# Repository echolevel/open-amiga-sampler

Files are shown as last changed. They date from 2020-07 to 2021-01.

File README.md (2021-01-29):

# OPEN AMIGA SAMPLER

## Open source schematics, parts lists and documentation for building a generic 8bit/mono Amiga parallel port sound sampler

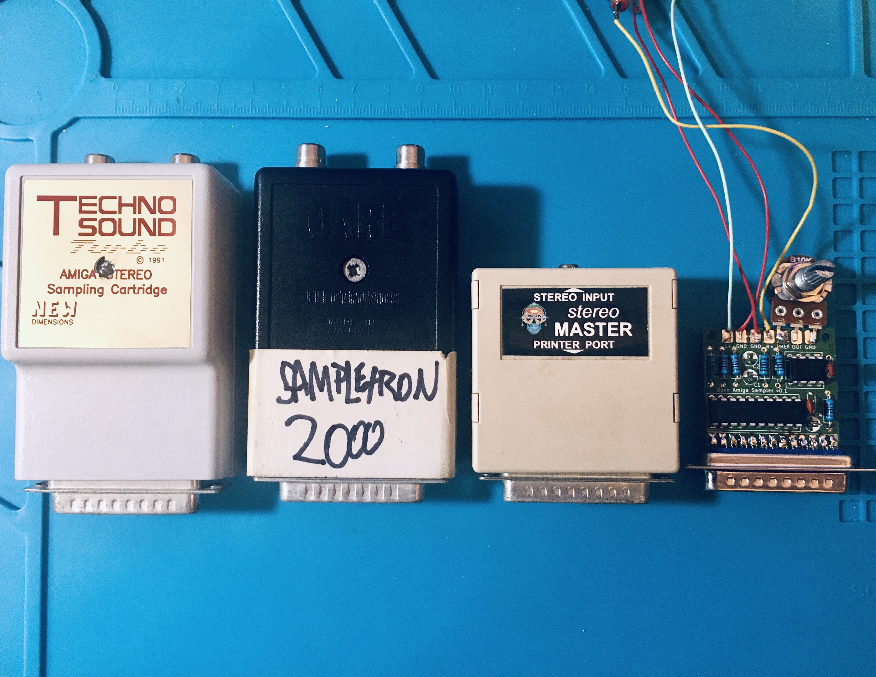
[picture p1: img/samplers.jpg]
samplers


Amiga parallel port sound samplers are simple hardware devices from the late 80s/early 90s which allowed users to digitally record audio to their home computer and represented a revolution in DIY music production. They were once cheap and ubiquitous, but they're increasingly expensive and hard to find as the popularity of retro computing continues to rise.

OAS is an open source PCB and case design for a cartridge-style mono sampler geared towards use with Soundtracker and Protracker-style software. It is easy to make, cheap to produce, and thanks to its built in preamp with hardware gain control it can deliver higher quality results than the average vintage sampler.

Please read the wiki for more information!

### [OAS Wiki Home](https://github.com/echolevel/open-amiga-sampler/wiki)

### Background

***
* [What are Amiga samplers?](https://github.com/echolevel/open-amiga-sampler/wiki/What-are-Amiga-samplers%3F)
* [Why build more?](https://github.com/echolevel/open-amiga-sampler/wiki/Why-build-more%3F)

### Development

***
* [How do they work?](https://github.com/echolevel/open-amiga-sampler/wiki/How-do-they-work%3F)
* [⚠️ WARNING](https://github.com/echolevel/open-amiga-sampler/wiki/%E2%9A%A0%EF%B8%8F-WARNING)
* [That WARNING sounds serious. How did you test your design without risking Amiga hardware?](https://github.com/echolevel/open-amiga-sampler/wiki/That-WARNING-sounds-serious.-How-did-you-test-your-design-without-risking-your-Amiga-hardware%3F)
* [Why is this sampler design mono, not stereo?](https://github.com/echolevel/open-amiga-sampler/wiki/Why-is-this-sampler-design-mono,-not-stereo%3F)
* [What's the aim in terms of quality and application?](https://github.com/echolevel/open-amiga-sampler/wiki/What's-the-aim-in-terms-of-quality-and-application%3F)
* [What about those edge cases? Who is OAS not aimed at?](https://github.com/echolevel/open-amiga-sampler/wiki/What-about-those-edge-cases%3F-Who-is-OAS-not-aimed-at%3F)
* [How compatible is OAS with existing software? (Work in progress, submissions welcome)](https://github.com/echolevel/open-amiga-sampler/wiki/How-compatible-is-OAS-with-existing-software%3F-(Work-in-progress,-submissions-welcome))
* [Current status](https://github.com/echolevel/open-amiga-sampler/wiki/Current-status)

### Production & Availability

***
* [Availability](https://github.com/echolevel/open-amiga-sampler/wiki/Availability)
* [DIY assembly](https://github.com/echolevel/open-amiga-sampler/wiki/DIY-assembly)

### Appendices

***
* [Appendix A: Sample rates deep-dive](https://github.com/echolevel/open-amiga-sampler/wiki/Appendix-A:-Sample-rates-deep-dive)
* [Appendix B: Sampling duration deep-dive](https://github.com/echolevel/open-amiga-sampler/wiki/Appendix-B:-Sampling-duration-deep-dive)

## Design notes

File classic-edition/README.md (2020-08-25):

# OPEN AMIGA SAMPLER CLASSIC EDITION

Kicad files for the original through-hole version of Open Amiga Sampler and OpenSCAD/STL files for the 3D-printable case.

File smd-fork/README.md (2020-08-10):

# OPEN AMIGA SAMPLER

## Overview

Here you can find the schematic and a PCB layout for Open Amiga Sampler in KiCAD format. Additionally, the schematic is available as a PDF.
The design consists of an inverting opamp circuit with variable gain which feeds an ADC. The DB25's strobe pin is connected to the ADC and initiates a conversion when it goes low. The ADC's outputs are connected to the data pins of a DB25 connector, which also provides power and ground. 

## BOM

* 1x Maxim ADC0820CCM+ (SOIC-20 Package) - mouser P/N  700-ADC0820CCM
* 1x Microchip MCP6001T-I/OT (SOT-23-5 package) - mouser P/N 579-MCP6001T-I/OTVAO
* 1x DB25 plug connector
* 2x RCA receptacles
* 1x 0805 330ohm resistor 
* 5x 0805 1kohm resistors
* 1x 10kohm exponential potentimeter
* 1x 4x5.3mm 47uf electrolytic capacitor
* 2x 10uf Tantalum Case A or 1206 capacitors
* 2x 0805 0.1uf capacitors

### Substitutions

The 10kohm potentiometer will give between 1x and 10x gain. A larger potentiometer can be substituted to enable a large maxium gain. The RCA receptacles can be replaced by a stereo jack receptacle if preferred. It is likely that both ICs could be substituted for similar chips with identical pinouts, but these are the models that we have tested and confirmed to work.

## Soldering

All on board components are surface mount but nothing smaller than 0805 and should be relatively easy to solder even for someone with a good base level of soldering and a bit of practice. The MCP6001 is a SOT-23-5 with a ~1mm pitch and represents the smallest component on the board. the Pot and RCA receptacles can be soldered with wire leads from the through hole pads

## Case

This board is intended to fit inside a standard DB25 D-Sub shell. (a regular common grey one) but due to it's small size, a larger enclosure can also be used and a custom 3D printed one may get produced as well.

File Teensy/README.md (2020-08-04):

## Teensy Amiga Sampler Tester

We used a Teensy 3.5 dev board to build a circuit that let us test original sampler carts, and also our prototype builds of OAS, without the risk of damaging our Amiga hardware.

The .ino is annotated with hopefully enough clues to get you going, though I'll make a diagram when I have time.

Some notes:
* the use of non-sequential digital pins for reading data is due to the way GPIO is laid out in the bare-metal Teensy architecture - using the pins I specify allows you to do a FAST byte read (doing it the slow way is too slow for our purposes)
* you don't really need to be alternating the STATUS and PAPER_OUT high/low if you're testing a mono sampler, as these are used to flip most cheap stereo samplers' quad bilateral switch ICs (to alternate the ADC's input providing data bytes in stereo with only one ADC). Setting one as high and the other as low and then leaving them should be fine. You can also do this to get mono (ie either left or the right channel) audio from a stereo sampler
* the STROBE, STATUS and PAPER_OUT signals need to be raised from Teensy's 3.3v output level to the 5v that the Amiga needs. This can be done with a bi-directional logic level converter, ideally with 4 channels. You can feed the converter the 5v it needs from a small hole next to the Teensy 3.5's USB input (refer to your Teensy's documentation). This hole usually won't align to a breadboard, so it's probably best to solder your 5v wire to it..
* be sure to wire up EVERY ground pin on the DB25 connector properly (see the Amiga parallel pinout below)
* the DB25 connector also needs 5v - again, get this from the Teensy's USB input.

### Amiga Parallel Pin Reference

Remember: we're mimicking an Amiga's parallel port so our female DB25 connector, wired up to the Teensy, is what a sampler sees when it's plugged into the real thing.

| DB25 Pin | Teensy pin | Purpose | Notes |
|-----|----|---|---|
|1| 9 | STROBE | must be at +5v reference level |
|2| 2 | Data 0 | |
|3| 14 | Data 1 | |
|4| 7 | Data 2 | |
|5| 8 | Data 3 | |
|6| 6 | Data 4 | |
|7| 20 | Data 5 | |
|8| 21 | Data 6 | |
|9| 5 | Data 7 | |
|10| | ACK | unused |
|11| | BUSY | unused |
|12| 10 | PAPER_OUT | must be at +5v ref level |
|13| 11 | SELECT | must be at +5v ref level |
|14| VUSB | +5V |
|15| | | not connected  |
|16| | RESET | unused |
|17| GND | GROUND |
|18| GND |  GROUND |
|19| GND |  GROUND |
|20| GND |  GROUND |
|21| GND |  GROUND |
|22| GND |  GROUND |
|23| GND |  GROUND |
|24| GND |  GROUND |
|25| GND |  GROUND |

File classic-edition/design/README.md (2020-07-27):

# OPEN AMIGA SAMPLER

## Overview

Here you can find the schematic and a PCB layout for Open Amiga Sampler in KiCAD format. Additionally, the schematic is available as a PDF.
The design consists of an inverting opamp circuit with variable gain which feeds an ADC. The DB25's strobe pin is connected to the ADC and initiates a conversion when it goes low. The ADC's outputs are connected to the data pins of a DB25 connector, which also provides power and ground. 

## BOM

* 1x Maxim ADC0820CCN+
* 1x Microchip MCP6002-I/P
* 1x DB25 plug connector
* 2x RCA receptacles
* 1x 330ohm resistor
* 5x 1kohm resistors
* 1x 10kohm exponential potentimeter
* 1x 47uf capacitor
* 2x 10uf capacitors
* 2x 0.1uf capacitors

### Substitutions

The 10kohm potentiometer will give between 1x and 10x gain. A larger potentiometer can be substituted to enable a large maxium gain. The RCA receptacles can be replaced by a stereo jack receptacle if preferred. It is likely that both ICs could be substituted for similar chips with identical pinouts, but these are the models that we have tested and confirmed to work.

## Soldering

All components are through-hole and should be relatively easy to solder even for a novice. Some components can be soldered to the back of the board and folded down to make the overall unit slimmer. One possible configuration is to solder C1, C2, C3 and C5 to the back of the board, and fold C4 down onto the front footprint of C3. We recommend soldering the DB25 connector first, followed by the passive components and leads, and finally the ICs. This reduces the chance of damaging the ICs with excessive heat.

## Case

We are working on a compact 3D printed case in an approriate form factor for all Amiga computers. You may be able to find an appropriate enclosure to build the device into, but if you intend to plug the device directly into your Amiga you will need to make sure that ports adjacent to the parallel port will not be impeded.

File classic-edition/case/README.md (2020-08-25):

# OPEN AMIGA SAMPLER CLASSIC EDITION CASE

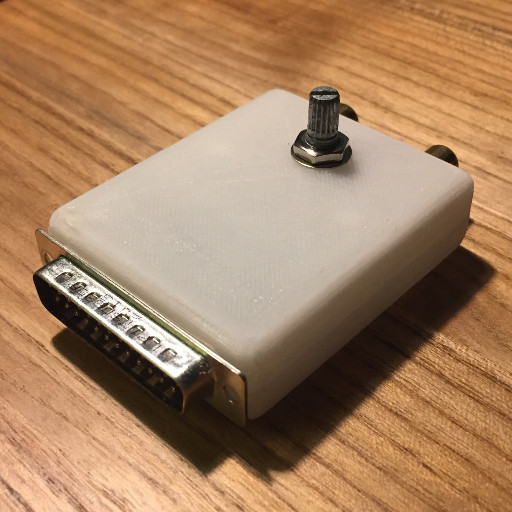
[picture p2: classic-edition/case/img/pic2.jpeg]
front

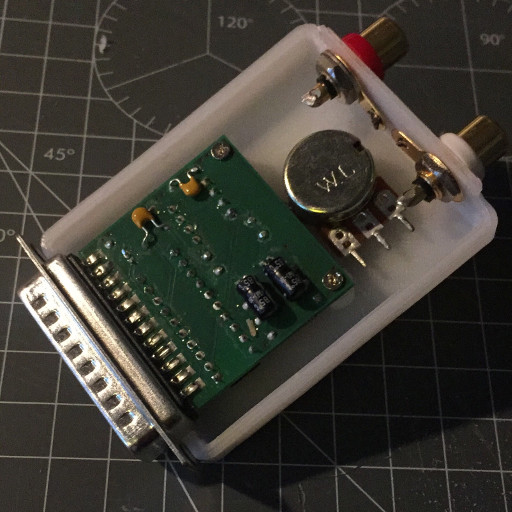
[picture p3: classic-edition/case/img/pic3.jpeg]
back

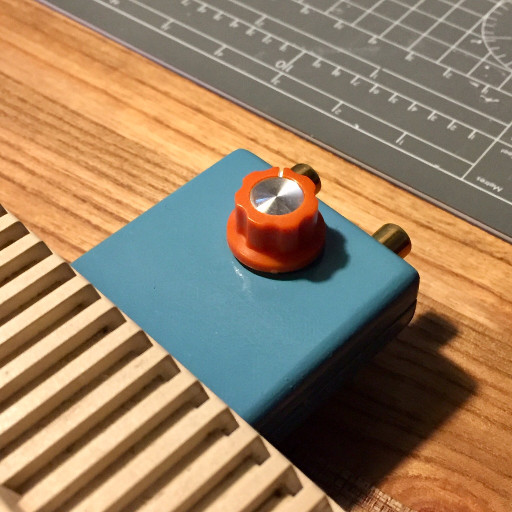
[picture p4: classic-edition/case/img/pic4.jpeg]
painted


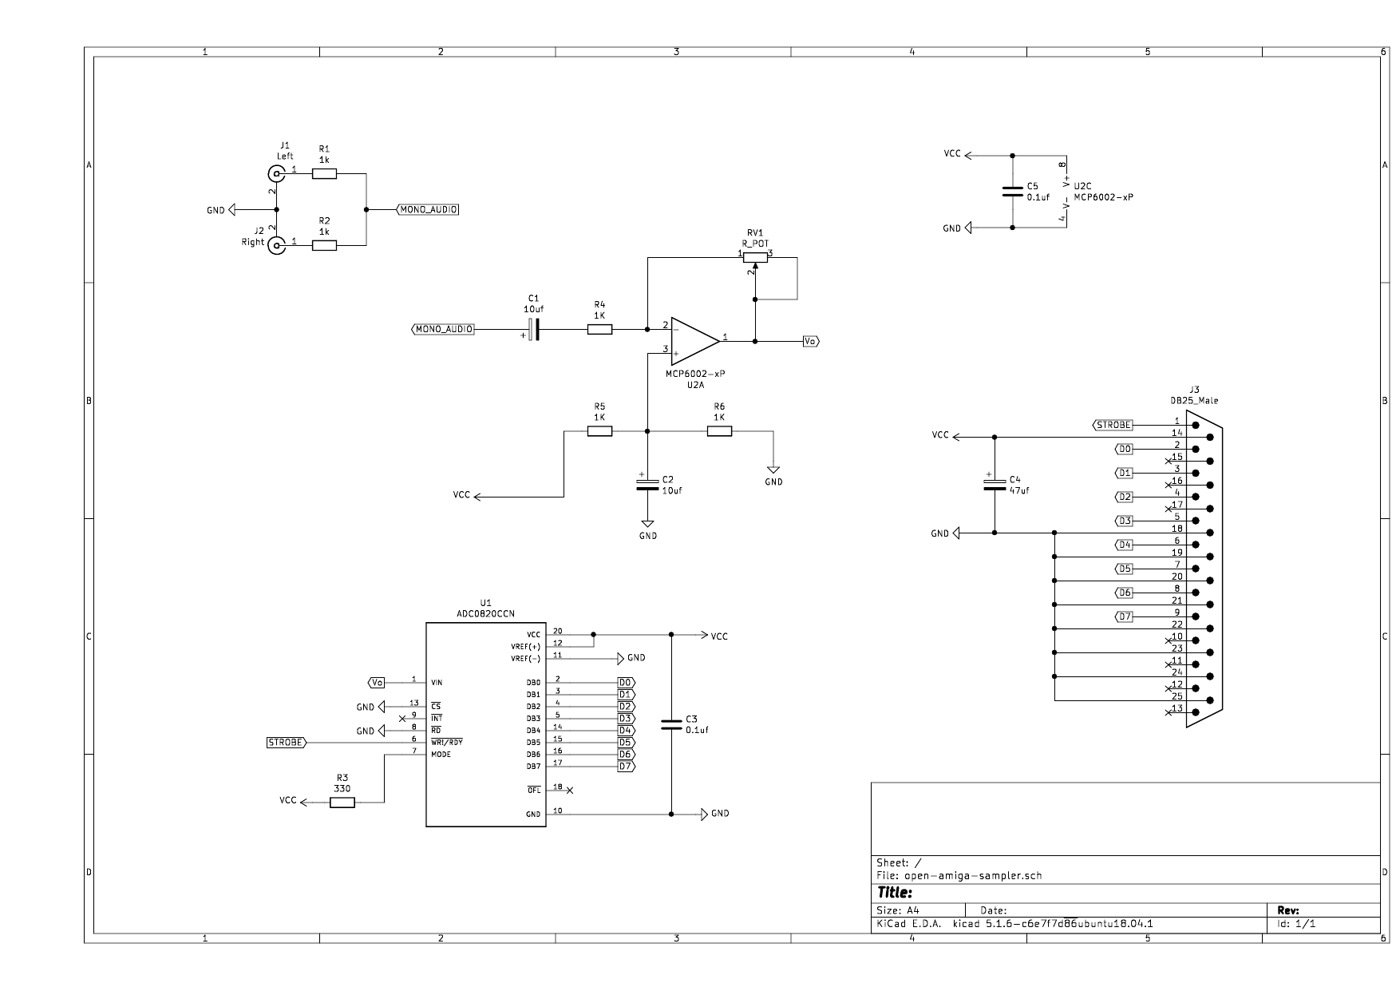
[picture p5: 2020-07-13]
img/schematic.png

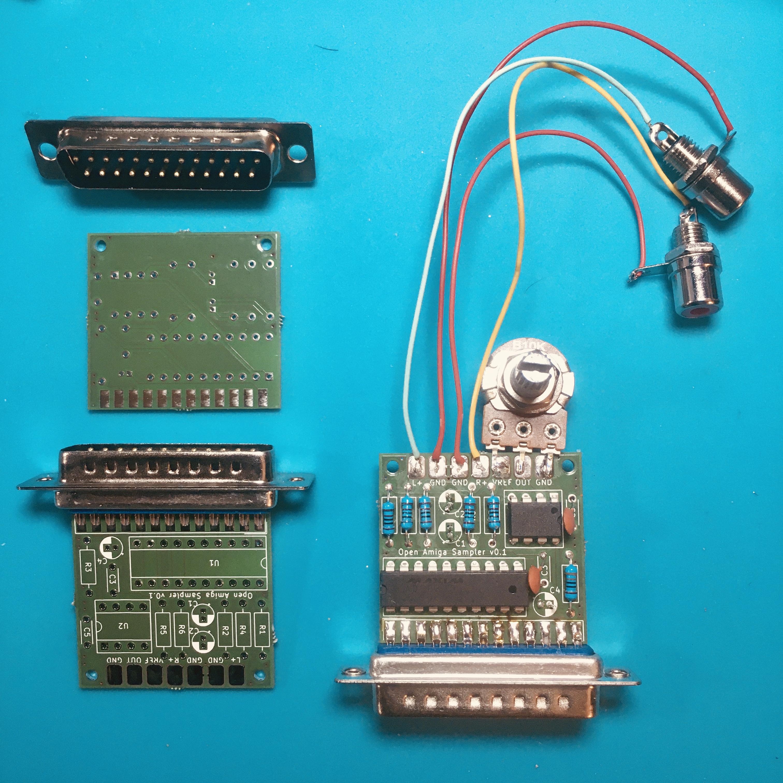
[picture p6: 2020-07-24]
img/oas_pcb.jpg

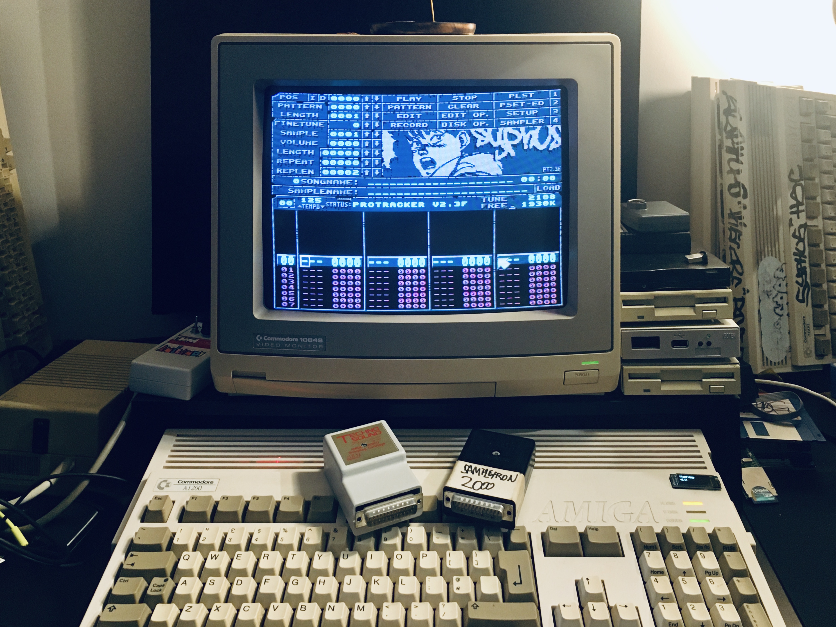
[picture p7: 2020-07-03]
img/amigawide.jpg

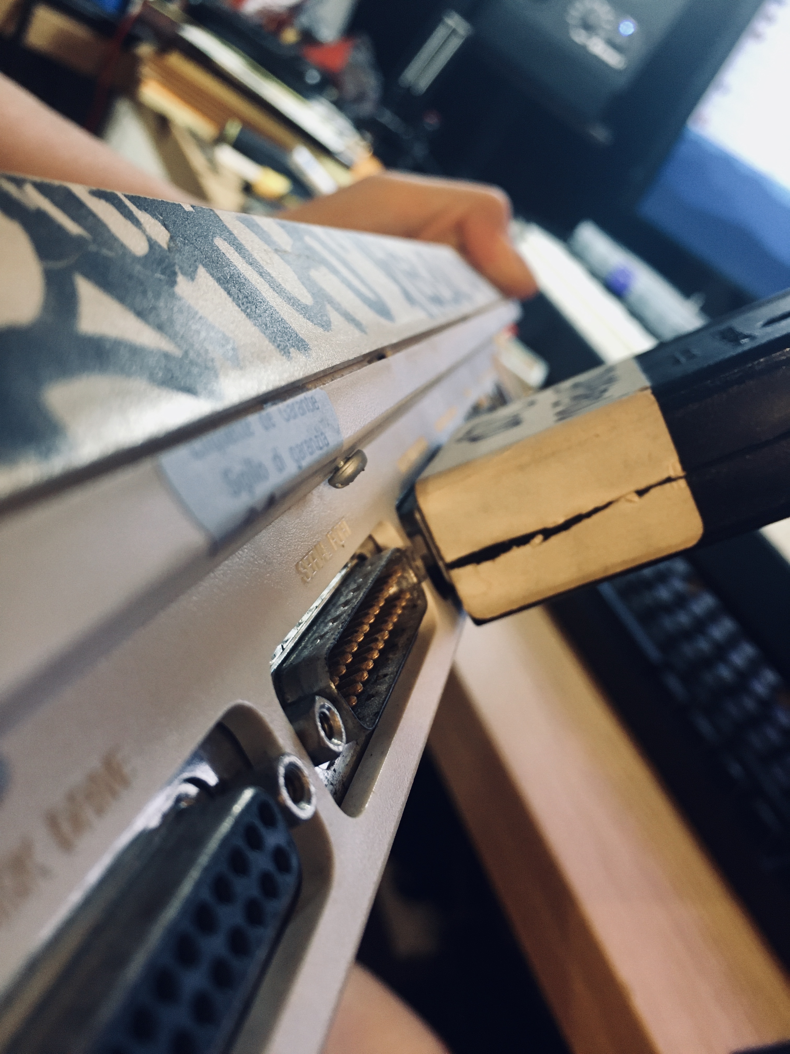
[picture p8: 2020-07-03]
img/amigaio.jpg

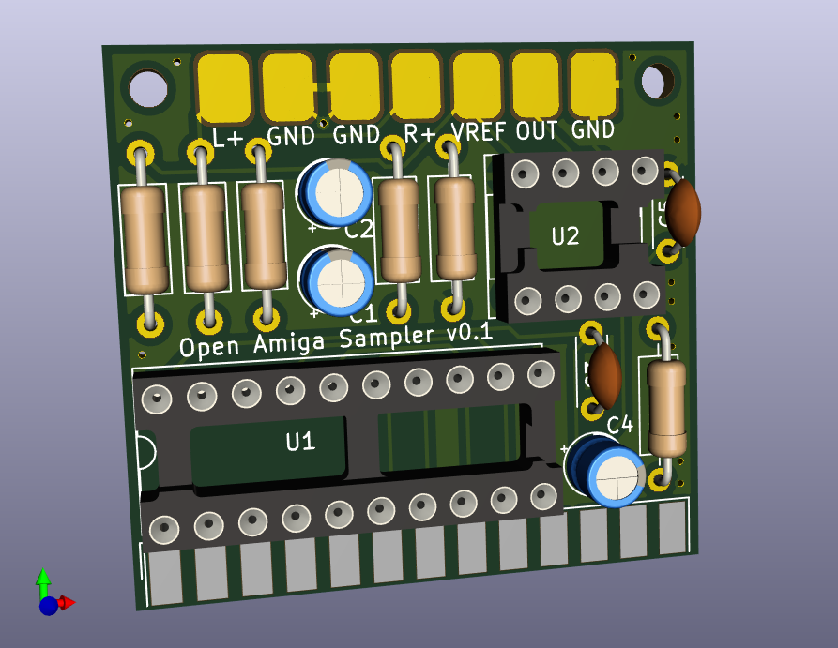
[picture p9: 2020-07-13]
img/pcb.png

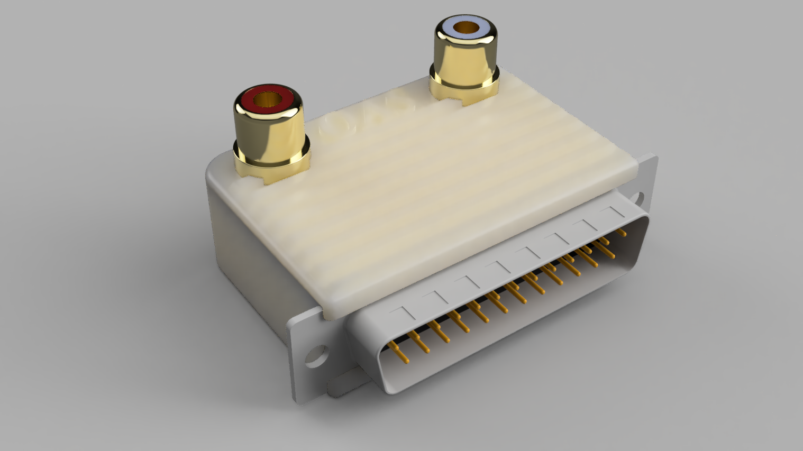
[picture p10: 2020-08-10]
smd-fork/case render.png

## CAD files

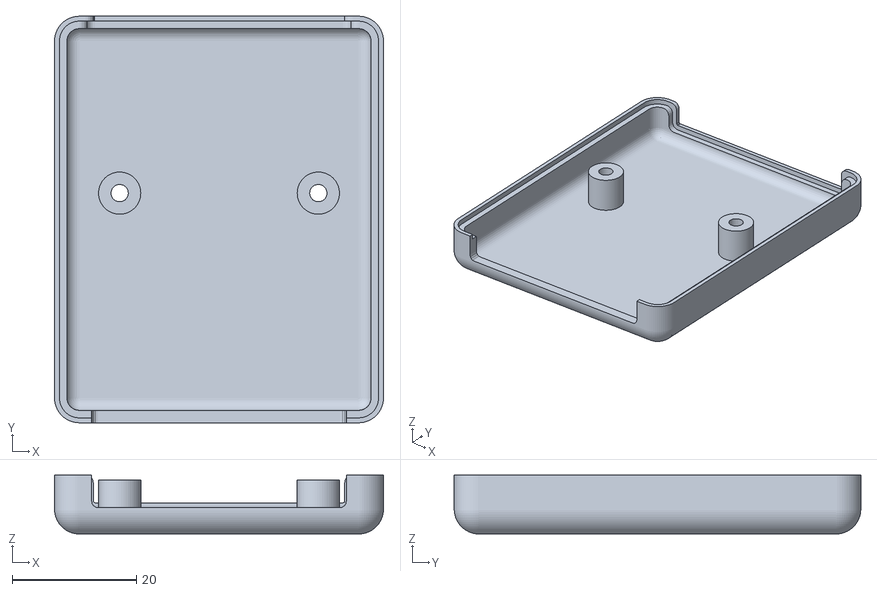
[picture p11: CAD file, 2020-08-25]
classic-edition/case/open-amiga-sampler-bottom.stl
53.0 x 65.5 x 9.50

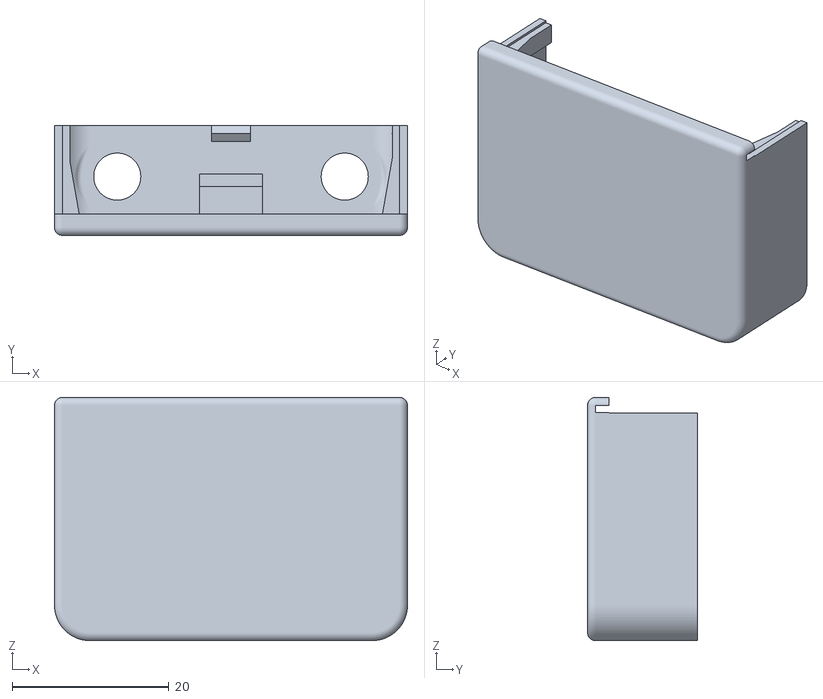
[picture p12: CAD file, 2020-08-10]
smd-fork/case models/OAS-lower-shell.stl
45.0 x 14.0 x 31.0

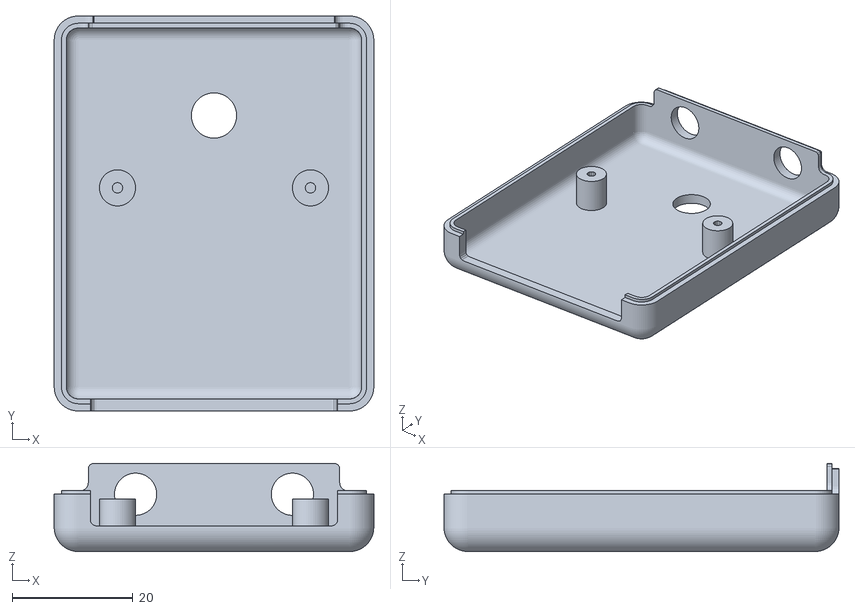
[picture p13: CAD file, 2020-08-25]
classic-edition/case/open-amiga-sampler-top.stl
53.0 x 65.5 x 14.6

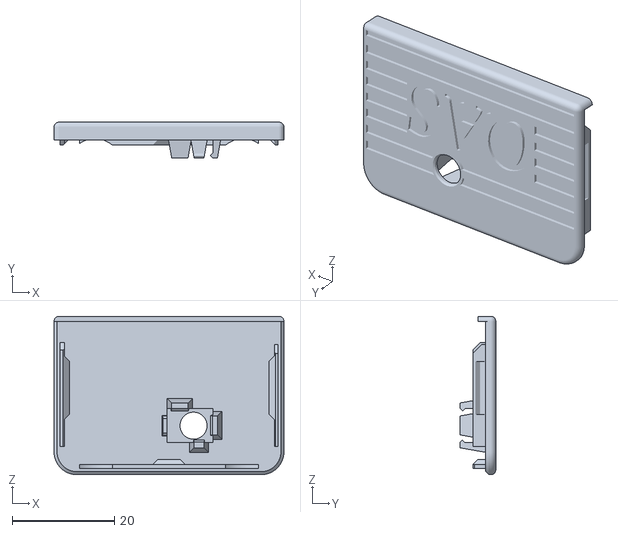
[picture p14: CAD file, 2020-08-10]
smd-fork/case models/OAS-Top shell.stl
45.0 x 7.00 x 31.0

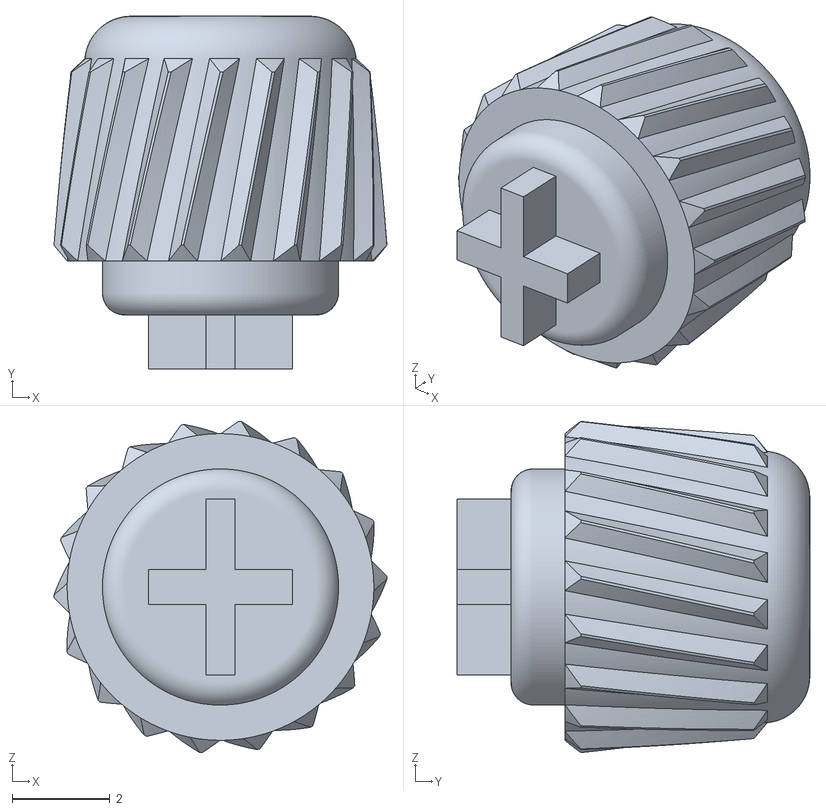
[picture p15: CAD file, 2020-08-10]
smd-fork/case models/OAS-trimmer-knob.stl
6.80 x 7.20 x 6.77

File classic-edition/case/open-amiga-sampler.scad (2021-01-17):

$fa = 1;
$fs = 0.4;

use <MCAD/boxes.scad>

db25Width = 41;

boxRadius = 4;
boxWidth = 54;//db25Width + boxRadius * 2 + 2;
boxHeight = 19;
boxDepth = 65.5;
boxWallThickness = 2;
lipGap = 0.4;
wedgeChunkiness = 3.0;
wedgeProtrusion = 2.0;
pcbThickness = 1.6;

module outerShell() {
    roundedBox(size = [boxWidth, boxDepth, boxHeight], radius = boxRadius, sidesonly = false);
}

module innerShell() {
    roundedBox(size = [ boxWidth - boxWallThickness * 2, 
                        boxDepth - boxWallThickness * 2, 
                        boxHeight - boxWallThickness * 2],
                        radius = boxRadius - boxWallThickness, sidesonly = false);
}

module fullOuterCase() {
    difference () {
        difference () {
            difference() {
                outerShell();
                innerShell();
            }

            // DB25 hole
            translate([0, -(boxDepth - boxWallThickness) / 2, 0])
                rotate([90, 0, 0])
                    roundedBox(size = [db25Width, 10.5, boxWallThickness + 1], radius = 1, sidesonly = true);
        }
    }
}

module pcb() {
    difference() {
        cube([37.5, 34.0, pcbThickness], center = true);
        union() {
            translate([-37.5 * 0.5 + 2.5, 34.0 * 0.5 - 2.5, 0.0])
                cylinder(h = pcbThickness + 2, r = 2.25 * 0.5, center = true);
            translate([37.5 * 0.5 - 2.5, 34.0 * 0.5 - 2.5, 0.0])
                cylinder(h = pcbThickness + 2, r = 2.25 * 0.5, center = true);
        }
    }
}

module screwParts(top, subtract) {
    screwThreadRadius = 1.0;
    screwHeadRadius = 2.5;
    screwClearance = 0.4;
    
    for (x = [-16, 16])
        translate([x, -boxDepth * 0.5 + 37, 0]) {
            if (top == false) {
                if (subtract == false) {
                    translate([0, 0, boxHeight * 0.5 - epsilon])
                        rotate([180, 0, 0])
                            cylinder(r = screwHeadRadius + boxWallThickness, screwHeadRadius - (screwThreadRadius - screwClearance));
                    translate([0, 0, pcbThickness * 0.5 - epsilon])
                        cylinder(r = screwThreadRadius + screwClearance + boxWallThickness, h = (boxHeight - pcbThickness) * 0.5);
                }
                else {
                    translate([0, 0, boxHeight * 0.5 + epsilon])
                        rotate([180, 0, 0]) {
                        // Countersink
                            cylinder(r1 = screwHeadRadius, r2 = screwThreadRadius + screwClearance, h = screwHeadRadius - (screwThreadRadius + screwClearance));
                            // Hole
                            cylinder(r = screwThreadRadius + screwClearance, h = boxHeight * 0.5);
                    }
                }
            }
           
            if (top == true) {
                if (subtract == false) {
                    difference() {
                        translate([0, 0, pcbThickness * 0.5])
                            cylinder(r = screwThreadRadius + boxWallThickness, h = (boxHeight - pcbThickness) * 0.5 - boxWallThickness + epsilon);
                        cylinder(r = screwThreadRadius - 0.125, h = (boxHeight - pcbThickness) * 0.5 - boxWallThickness);
                    }
                }
            }
        }
}

epsilon = 0.001;

module connectorPanel(top, subtract) {
    curveRadius = 1.25;

    if ((top == true && subtract == false) || (top == false && subtract == true)) {
        union() {
            // Inner
            size0 = (top ? (boxWallThickness - lipGap) : (boxWallThickness + lipGap));
            translate([0, boxDepth * 0.5 - boxWallThickness + size0 * 0.25, 0]) {
                rotate([90, 0, 0])
                    roundedBox(size = [
                            boxWidth - boxRadius * 2 - curveRadius * 2.0 - (top ? lipGap * 2.0 : 0),
                            boxHeight - boxRadius * 2 - (top ? lipGap * 2.0 : 0),
                            size0 * 0.5 + (subtract ? epsilon : 0)
                        ],
                        sidesonly = true,
                        radius = curveRadius - (top ? lipGap : 0));

                for (a = [0, 180])
                    rotate([(top ? 0 : 180), 0, a]) {
                    x = -boxWidth * 0.5 + boxRadius + (top ? lipGap : 0);
                    z = -(boxWallThickness * 0.5 - (top ? lipGap : 0));
                    
                    difference() {
                        translate([ x + curveRadius * 0.5,
                                    0,
                                    z - curveRadius * 0.5])
                            cube([curveRadius + epsilon, size0 * 0.5 + epsilon, curveRadius + epsilon], center = true);
                        translate([x, 0, z - curveRadius])
                            rotate([90, 0, 0])
                                cylinder(r = curveRadius, h = size0 * 0.5 + 1.0, center = true);
                        
                    }
                }
            }
            
            // Outer
            size1 = (top ? (boxWallThickness + lipGap)  : (boxWallThickness - lipGap));
            translate([0, boxDepth * 0.5 - size1 * 0.25, 0]) {
                rotate([90, 0, 0])
                    roundedBox(size = [
                            boxWidth - boxRadius * 2 - boxWallThickness - curveRadius * 2.0 - (top ? lipGap : 0),
                            boxHeight - boxRadius * 2 - boxWallThickness - (top ? lipGap : 0),
                            size1 * 0.5 + (subtract ? epsilon : 0)
                        ],
                        sidesonly = true,
                        radius = curveRadius - boxWallThickness * 0.5);
                for (a = [0, 180])
                    rotate([(top ? 0 : 180), 0, a])
                        difference() {
                            x = -boxWidth * 0.5 + boxRadius + (top ? lipGap * 0.5 : 0);
                            translate([x + curveRadius + lipGap, 0, -curveRadius * 0.5])
                                cube([curveRadius, size1 * 0.5 + epsilon, curveRadius + epsilon], center = true);
                            translate([x + boxWallThickness * 0.5, 0, -curveRadius])
                                rotate([90, 0, 0])
                                    cylinder(r = curveRadius, h = size1 * 0.5 + 1.0, center = true);
                        }            
            }
        }
    }
    
    if (top == true && subtract == true) {
        // Phono hole
        for (x = [-14, 14])
            translate([x, (boxDepth - boxWallThickness) * 0.5, 0])
                rotate([90, 0, 0])
                    cylinder(r = 3.5, h = boxWallThickness + 0.01, center = true);
    }
}

module top() {
    potHoleHeight = boxWallThickness * 2.0;
    
    difference() {
        union() {
            difference() {
                union() {
                    difference() {
                        fullOuterCase();
                        union() {
                            translate([0, 0, -boxHeight * 0.5])
                                cube([boxWidth + 1, boxDepth + 1, boxHeight], center = true);
                            innerShell();
                        }
                    }
                    intersection() {
                        translate([0, 0, lipGap])
                            roundedBox(size = [
                                    boxWidth - (boxWallThickness + lipGap),
                                    boxDepth - (boxWallThickness + lipGap),
                                    boxWallThickness
                                ],
                                radius = boxRadius * 0.5 + (boxWallThickness - lipGap) * 0.5,
                                sidesonly = true);
                        fullOuterCase();
                    }
                    screwParts(top = true, subtract = false);
                    // Pot hole spacer
                    translate([0, boxDepth * 0.5 - boxRadius - 12.5, boxHeight * 0.5 - potHoleHeight * 0.5 - epsilon])
                        cylinder(h = potHoleHeight, r = 3.75 + 3.0, center = true);
                }
                union() {
                    // Pot hole
                    translate([0, boxDepth * 0.5 - boxRadius - 12.5, boxHeight  * 0.5 - potHoleHeight * 0.5])
                        cylinder(h = potHoleHeight + 0.01, r = 3.75, center = true);
                        screwParts(top = true, subtract = true);
                }
            }
            intersection() {
                union() {
                    connectorPanel(top = true, subtract = false);
                }
                outerShell();
            }
        }
        connectorPanel(top = true, subtract = true);
    }
}
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

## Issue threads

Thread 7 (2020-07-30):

Add phono preamp?

kikendo, 2020-07-30:
Hey guys, interesting project here!

I just thought it'd be neat to have a phono preamp in here to be able to sample straight from a turntable without the need of a phono preamp in the middle.
Since there's really not many ways to improve sampler functionality in the Amiga, I thought this'd be a neat idea.

Feel free to throw it in the trash xD

echolevel, 2020-07-30:
Thanks! I do like this idea, and I'm wondering how best it could be done. I guess it would need a built-in RIAA filter, and I'm not sure whether there are single-chip solutions for that (at least, ones that can run on ~5v). I've seen lots of DIY phono preamps that are built like tanks and powered by enormous switching PSUs but that might be a red herring - the designers and hobbyists building those things might have other requirements in mind, in terms of SNR or power output.

But this also reminds me that I haven't got around to just sticking a turntable right into the OAS yet. I'm sure it'll sound a bit grim without the RIAA curve compensation, but I'm curious! It would be nice to save on a power outlet and free up some phono cable runs by being able to go turntable direct to sampler...

kikendo, 2020-07-30:
You managed to change the label now, cool! ;)
And yeah just a wild idea, but if you can pull it off, it'd definitely give it an edge over any other sampler ever made.

j0hnlittle, 2020-08-08:
Maybe as a starting point, there is this application note from Maxim: [USB-POWERED HIGH PRECISION HI-FI PHONO PREAMP](https://www.maximintegrated.com/en/design/technical-documents/app-notes/1/1931.html)

> This design idea shows a 3.3V powered phone preamplifier with RIAA equalization curve. The advantage is the low power, low voltage single supply solution. It is done with a MAX4478, a quad, low-noise, rail-to-rail op amp.

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

> A small linear regulator, the MAX8877, regulates the noisy +5V from the USB supply down to +3.3V

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

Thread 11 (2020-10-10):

Gerber file

Milesy, 2020-10-10:
Hi, I would like to print a pcb using pcb but having issues trying to generate the Gerber file using Kicad.

Could you please supply the required config or a Gerber file?

Many thanks

Chris

Milesy, 2020-10-10:
Note - for the classic edition, not surface mount

abrugsch, 2020-10-10:
By default KiCAD doesn't generate drill files so I expect that's your problem, so after you generate Gerber's from the default options click the generate drill files button and again default options should be fine. Alternatively if you use OSH Park you can just submit the kicad_pcb file and they take care of the rest

abrugsch, 2020-10-13:
@Milesy here's a plot of the classic gerbers. i've checked them with OSH park, they should be fine in any of the PCB fabs
[OAS-Gerbers.zip](https://github.com/echolevel/open-amiga-sampler/files/5370184/OAS-Gerbers.zip)

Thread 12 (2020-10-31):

Wrong MCP6001 package in SMD BOM

cnvogelg, 2020-10-31:
The schematic and board uses a MCP6001U and not a plain one without U. The U type has a different pinout (see data sheet)

So the corrcet Mouser part would be

579-MCP6001UT-I/OT

abrugsch, 2021-01-06:
Oh yes. I had it updated in my local copy but hadn't pushed the change yet. I'll do a PR

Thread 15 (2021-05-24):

okay to sell?

smartroad, 2021-05-24:
Hi! I wanted to make one of these for myself but have to buy several PCBs. I was wondering if it would be okay to sell the remainder, maybe with the components as a kit?

abrugsch, 2021-05-24:
Which one is it? The SMD version hasn't been tested as working yet. @echolevel got one working but it was very very quiet even with gain turned right up.

I will be investigating shortly now my makerspace is open again.

If it's the regular through hole variant then I don't see a problem selling off the spares.

smartroad, 2021-05-24:
It would be the through hole. I tend to do TH as I have a hot air wand and while I do some limited SMD soldering that way, I prefer through hole :)

Ruxton, 2021-05-26:
based on https://github.com/echolevel/open-amiga-sampler/wiki/Availability i took it as gospel that it was OK to build up and sell.  made 5 boards, sold 2 bare, kept 2 for myself and traded one with a mate. A few people in the local Amiga group expressed interest in obtaining some pre-built ones, so I figured if this run worked well I'd order a few more boards and do some assemblies for them.

mnstrmnch, 2021-05-26:
Thank you for checking, and yes please go ahead and do as you wish with the through-hole version. It would be cool to see your results too - we're aware of people having made their own but (as far as I know) haven't seen any in the wild yet :)

smartroad, 2021-05-26:
Great thanks! I have the board on order (be a couple of weeks as I am cheap for postage lol). Modified the board a little to move the e-caps to the underside on the board (hope that's okay too!). Got parts on order so hopefully should have one built in a few weeks.

echolevel, 2021-05-27:
Good stuff! Might be worth paraphrasing a response I gave this week to someone who emailed about making some to sell on eBay (also in Australia, but not @Ruxton!)

My initial run has stalled temporarily, partly because I'm flat-out with work but also because I've got no ventilated space to do a batch of soldering in until I move house, hopefully soon. The units in that run are all spoken for - I've kept a spreadsheet that's as fair as I can make it which lists usernames of everyone who's shown an interest via YouTube/Instagram/Twitter replies, sorted in the chronological order of those replies. The idea is for me to contact those people via those platforms when the units are ready and see if they're still interested.

If somebody else makes a batch before I finish mine, I'm sure a bunch of those people will be very pleased to get one quicker. I'm all for that: the point of this project is to get them into people's hands and help them avoid eBay price-gouging on retro kit! That'll free up some slots on my list. And even if it frees up ALL the slots on my list (ie the market is saturated and I can no longer shift my units), so be it :)

So it follows that if anyone reading this _does_ want to make up a batch to sell, let me know in this thread and I'll do my best to inform the people on my list that there are units available if they don't want to wait for mine.

P.S. I have no idea what constitutes market saturation for this product. It could be 100 units, it could be a dozen. Retro computing is weird at the moment - lots of enthusiastic newcomers with disposable income, which is great, but I detect a trend of people buying a peripheral for every hole, as it were, regardless of whether they intend to use it very much or at all - more out of completeness. That's absolutely fine, I'm not bothered what people do with their own stuff; I'm just saying it's why I struggle to estimate how many people in the world will want one of these.

So as long as no prospective manufacturers go nuts and order e.g. 500 boards and find themselves out of pocket (I think it's safe to say that would be a wild overestimation), I think a handful of us doing a dozen or couple of dozen units will work out nicely!

smartroad, 2021-05-27:
I've only ordered 5 pcbs so will have 4 spares. Also ordered enoigh parts for all as well. I might pop it onto Tindie just to ease payments etc for me. Not really interested in making a profit other than to cover my time and testing!

I have an idea for a case as well and maybe a logo (I might be becoming too invested here haha!)

smartroad, 2021-05-28:
Once I have my first one built and validated, I can pop on there and see if anyone would like any of the others?

echolevel, 2021-05-28:
It's a good place to start if looking for interested buyers, for sure - just check the rules (probably pinned in the main channel) for protocol on offering things for sale, but I _think_ you can informally announce in the Amiga channel that you're selling. Lots of people in there are comfortable building their own too, so you might get interest in blank PCBs.

abrugsch, 2021-05-28:
@smartroad please be aware that on RMC discord there's a privilege to sell things that's RMC patron only...
RMC might not be the best place to organise that

smartroad, 2021-05-28:
@abrugsch that's rubbish :( well I'll put mine up on Tindie and people can find it there (or not!) I might pop a message on the hackaday article as well to say I have a few to sell.

smartroad, 2021-05-28:
While I wait for the PCBs to arrive I have been desinging a case and logo for the sampler. Here is the first version mocked up:
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

It is designed to just clip together so no need to fasteners hopefully. I miss measured the gain pot so this versions knob is to short. Also the fit is a little bit to tight causing the top and bottom parts to flex a little.

Next version will have increased fit between the clips holding it together and the knob will be increased in length.

Hope people like! ☺

smartroad, 2021-05-29:
Next version:
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

I'll also make a version that doesn't need dual/multi extrusion, although the text wouldn't be another colour of course.

smartroad, 2021-05-30:
I thought about making a label for the back of the case for basic instructions and info about the device/project. What do people think of the wording here:
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

Ruxton, 2021-06-04:
@smartroad  i really like your label, only grip is the spacing around the QR code vs. everything else.

smartroad, 2021-06-04:
@Ruxton cheers! Yeah I am not that happy with it. I think I'll see if QR codes need to be black on white and test if it works inverted 🤔 That would allow easier fitting without making it much smaller (it's only about 20mm square!)

smartroad, 2021-06-04:
@Ruxton
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
Tweaked QR code - inverting colours doesn't work on QR codes it seems LOL

echolevel, 2021-06-06:
Looks good! Big Mackie Big Knob energy 👍🏼

smartroad, 2021-06-10:
PCBs have arrived so will be building one at the weekend to test!

smartroad, 2021-06-13:
https://youtu.be/jzzcCFz7-dA

It lives!!!

echolevel, 2021-06-15:
Nice one! Great to see one out in the wild!

smartroad, 2021-06-16:
Planning to record a proper video over the weekend doing a bit of an overview. For selling, I am just waiting on an order of resistors as I didn't have any 330R's.

smartroad, 2021-06-19:
Overview video is currently rendering and I hope to have it up soon! I have a PAINFULLY slow internet connection so it may be a while even after rendering to get it fully uploaded and ready to go. I'll provide a link once I have it uploaded :)

smartroad, 2021-06-20:
Preview of video for those interested :) plan to release tomorrow (1pm BST)

echolevel, 2021-06-20:
Excellent!

The only thing I'd be picky about - purely in terms of technical pedantry, and not suggesting you make any changes - is the fact that the OAS' maximum sample rate is actually around 50Khz! Obviously there's an enormous pile of caveats involved, and you definitely wouldn't be able to run an Amiga program's display - let alone spectrum analysis - while sampling at those rates, but it can be done. Even in Protracker the practical upper limit is around 29Khz (A-3/B#3), and that's what you use if you've got chipmem to burn and you want the highest possible quality hi-hats :)

Needless to say, these intricacies are way more about the Amiga itself (and PAL/NTSC video timing, and the CIA chip) than about OAS and its chip specifically. [More details here](https://github.com/echolevel/open-amiga-sampler/wiki/Appendix-A:-Sample-rates-deep-dive).

Out of interest, I wonder what the maximum possible sample rate is on one of these A/D chips? Probably quite high (albeit still at 8bit). Some time when I can be arsed, I'll test it on my Teensy parallel-port-emulator jig.

smartroad, 2021-06-20:
Cheers! I will update the video and include a link to the page. I noticed I missed a couple of other bits off I wanted to say so have added those in as well.

Max sample rate, if I am reading the data sheet right, is about 400K or so (I made it 460K but I don't think I am including all of the timing delays)

echolevel, 2021-06-20:
Haha nice - I knew it was something preposterous and ultimately limited only by its internal silicon witchcraft, but couldn't recall what sort of ballpark it was in.

If you ever get the chance btw, it's a nice little exercise to try sampling a >16bit and >44.1Khz signal at the highest possible rate using Megalosound or similar and then comparing it to the source. If you choose a source that's sympathetic towards the reduction to 8 bits - e.g. pretty hot, a musically dense mix, not much dynamic range, definitely no subtle fades - you can get surprisingly impressive results.

Of course it's no more than that, an exercise, since you can't then play those samples back at the original frequency without also switching to the crazy-hi-frequency screenmode, but it's fun all the same.

smartroad, 2021-06-21:
Updated video on full release: https://youtu.be/Eji0Wg25V3g

echolevel, 2021-06-22:
Nice one! Just shared it on [Twitter](https://twitter.com/echolevel/status/1407248513407279108) so you might get some queries from people interesting in buying the other four...

pawelomega, 2021-09-06:
Im also finished my AOS. Im very happy. Working like a charm
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

hayesey, 2021-09-30:
Does anyone have a spare bare PCB they'd be willing to sell rather than me getting another batch made up?

pawelomega, 2021-10-02:
sorry. my 4 pcs all goes to Amiga friends.

smartroad, 2021-10-02:
> Does anyone have a spare bare PCB they'd be willing to sell rather than me getting another batch made up?

I think I may have a couple still here, if you are still in need I'll have a look! Have all the components as well I think!

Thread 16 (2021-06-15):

BOM more information about parts

pawelomega, 2021-06-15:
Hi. Im trying to build my fisrt own sampler but i need more info about used parts as:

1x 330ohm resistor - how many watts? 5,10,50,100 W
5x 1kohm resistors - also same as upper

1x 47uf capacitor - how many volts, 16,25,50,100 V and type - electrolytic capacitor or tantalum
2x 10uf capacitors - also same as upper
2x 0.1uf capacitors -also same as upper

thanks in advance for more important info for me.

echolevel, 2021-06-15:
Hi Pawel,

Capacitor voltage ratings are usually upper limits, beyond which the capacitor might burn out. Similarly, power (in Watts) ratings for resistors are upper limits. This circuit is extremely low voltage and low power, so for example a capacitor rated at 50V will be fine, but so will a capacitor rated at 63V or 100V - as long as the capacitance value is correct, and the capacitor is the correct physical size to fit into the circuit.

Similarly it shouldn't matter whether a resistor (in this circuit) is rated for 0.25W or 2W, since the circuit should never be handling that much power. We're looking at 5V from the Amiga's parallel port, which is enough top power the A/D chip and the op amp, and 24 mA (milliamps), which gives us a wattage of around 0.12, so neither the voltage nor the wattage in this circuit will come close to the limits of most of the resistors and capacitors that you'll find when searching for the BOM's specs!

As for electrolytic vs tantalum: electrolytics are cheaper and I don't think tantalum caps would make any noticeable improvement, given the relatively lo-fi audio quality we're dealing with here :)

Happy to hear from anyone else who might be better informed than me, but generally speaking as long as the components' W/V ratings exceed the throughput in the circuit, then variations in those ratings should be fine.

pawelomega, 2021-06-15:
Nice. PCBs are ordering. It's time to complet parts. Thanks !

pawelomega, 2021-08-05:
Hello again. I have problem to find 2x 10uf capacitors ceramic in my country.  Only tantal or electrolitic  Can i swap with electrolitic 10uF 50V ? but need know polarisation if possible.

gwEm303, 2021-08-18:
I would make C1 tantalum, the others can be electrolytic. Make sure the positive terminal is connected to the opamp.

Circuit all runs at 5v or below, so 6v or above capacitors will be fine.

1/8 watt resistors will be fine.

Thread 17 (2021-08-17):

Feedback on circuit

gwEm303, 2021-08-17:
Hope you don’t mind have some comments on the OAS circuit:

* Second unused op-amp (U2b) inputs are floating. This is in all likelihood fine, but it can affect power consumption and the slew rate of the first opamp. Would suggest grounding both inputs.

* Use of a tantalum bead rather than an electrolytic in the C1 position would improve audio quality slightly

* The OAS as I built it does have a small DC offset. This could be addressed by using a 10K resistor in R6, and a 9K1 resistor in the R5 position in series with a 2K2 preset resistor. Would allow the user to adjust their DC offset

* Minimum gain of the circuit actually is 0x rather than 1x

* There is no low pass filtering on the input. I think it would help sound quality to implement a LPF with a 14kHz cut off. You could achieve this simply with a first order RC filter on the output of U2a. However, this will only give a 6dB/octave roll off. Since U2b is unused you could design a 4th order (24dB/octave) low pass filter on the input which should be fairly tight. I discovered this when trying to sample from a CD. There was a very high frequency (inaudible) sound from the CD player, however due to aliasing on the OAS there was artefacts in the audible range. The TST cartridge also did this.

I am happy to help with this project going forward, I can be reached via the usual channels.

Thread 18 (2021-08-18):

Reverse polarity of C1

gwEm303, 2021-08-18:
The output of C1 is notionally at 2.5v, and the input is at 0v, therefore polarity of C1 needs to be switched to have the positive terminal connected to the op-amp

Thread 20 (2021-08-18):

Simple anti-aliasing filter

gwEm303, 2021-08-18:
rather than a straight connection between U2a and the ADC, a simple antialiasing filter of 100R and 100nF can be fitted.

The 100R is connected serially between U2a and the ADC. The 100nF is connected from the input of the ADC and ground.

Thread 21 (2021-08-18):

Better anti-aliasing filter

gwEm303, 2021-08-18:
Using the unused U2b we may implement this 18dB/octave anti-aliasing filter:

https://www.dropbox.com/s/mzd1efro0kk7ato/OAS%20cascaded%20antialiasing%20filter.jpg?dl=0

jnlundberg, 2024-08-12:
photo of soldered pcb would be great

gwEm303, 2024-08-12:
sorry, I can't take one of those at the moment

jnlundberg, 2024-08-13:
"The 1nF can be connected on the solder side of the PCB, between pins 4 and 5 of U2b."

-should this instead be pins 5 and 6 of U2b, as in the schematic?

butterrsoft, 2024-10-30:
This mod replaces the previous single-gang pot, is that correct? When implemented, does the new pot still dial in variable gain, and the filter follows? Or does it just adjust the filter, and the gain is fixed?

And no, jnlundberg, the cap is not shown between pins 5 and 6. It goes between 4 and 5 (4 being ground).

gwEm303, 2024-10-30:
> This mod replaces the previous single-gang pot, is that correct? When implemented, does the new pot still dial in variable gain, and the filter follows? Or does it just adjust the filter, and the gain is fixed?
>
> And no, jnlundberg, the cap is not shown between pins 5 and 6. It goes between 4 and 5 (4 being ground).

that’s right!

butterrsoft, 2024-10-30:
Err, sorry, that answer is a little confusing! So the new pot replaces the old one, and still adjusts the sample gain, yes?

gwEm303, 2024-10-30:
:-D

no, you end up with two pots : one for the gain and one for the anti-aliasing filter

butterrsoft, 2024-10-30:
So the old pot connects in after U2A pin 1 but before the leftmost 5k6 resistor, yes?

gwEm303, 2024-10-30:
the pot to adjust the filter is a dual gang pot and only does the filter. one gang of it connects after the first 5K6 and the other gang of it connects after the second 5K6

to control the gain there is a 100K log pot which is in the feedback loop of U2A (see “improved input stage”)

butterrsoft, 2024-10-30:
Righto, thanks for the pointers :)

jnlundberg, 2024-10-30:
Hey guys,  I never got this to work. Please let me know if succeed. Would be nice with a picture. And an updated schematic with all the mods. Not sure how to trouble shoot it. Pcb should be ok, I ordered with a midi interface pcb and it worked out fine.

butterrsoft, 2024-10-30:
I'm marking up a new schematic to make an smd pcb from. Not sure if the 3rd order filter will fit, but I can share the schematic when done.

jnlundberg, 2024-10-30:
I got parts to do a few more of this through hole so it'd be great if I van use the schematic with it

butterrsoft, 2024-10-31:
OAS schematics:
with 1st order filter - https://fastupload.io/f11ed2d0d8b00241
with 3rd order filter - https://fastupload.io/8083af4fe8b074d2

Both use the V.20 conventional input stage

jnlundberg, 2024-10-31:
Amazing, thnx a lot!

echolevel, 2024-10-31:
Good stuff, everyone! @butterrsoft - would you mind reporting back on whether you have success with either/both circuits? If you can confirm success, we can add the PDFs to the repo (if you give us permission, of course). Thanks!

gwEm303, 2024-11-24:
It’s just a low pass filter, not a high/low pass filter.

I would like to add a high pass filter to the circuit to have both options, but that’s not done.

The intention of the low pass filter is to remove whine and aliasing noise. so it’s possible the filter is working well!

butterrsoft, 2024-11-25:
Ahh, that's interesting. In which case, yes, the LPF works amazingly well! In this case i was able to mitigate the problem with 'better' source equipment, but that's not always going to be the case.

rain-fade, 2025-06-15:
> OAS schematics: with 1st order filter - https://fastupload.io/6788f0d7c0f750b3 with 3rd order filter - https://fastupload.io/49db4cdfce478cad
>
> Both use the v2.0 conventional input stage from gwEm303 :)

sadly both of these links resolve to scammy ads now.

butterrsoft, 2025-06-15:
> sadly both of these links resolve to scammy ads now.

[Schematic_OAS_v2.0-with-1st-order-filter.pdf](https://github.com/user-attachments/files/20748028/Schematic_OAS_v2.0-with-1st-order-filter.pdf)
[Schematic_OAS_v2.0-with-3rd-order-filter.pdf](https://github.com/user-attachments/files/20748027/Schematic_OAS_v2.0-with-3rd-order-filter.pdf)

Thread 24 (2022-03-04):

Research help: Looking for ZN427 Schematic (Amiga)

callimero, 2022-03-04:
Hi,

I am sorry to disturb this here :) I am looking for a specific schematic of a Ferranti ZN427 audio Digitizer I build for my Amiga 25 years ago (approx.). I am writing currently an article about it and need some more background.

It has a very primitive input stage, no OpAmp, just the ZN427 and a SN7414. I think I may had the instructions from an Amiga Magazin or a book. I found similar schematics in the 68000er magazin but not quite the exact one.

The digitizer is working on my A2000 (stuffed with all you could afford back in the days), a bit crackely. Not sure why.

I thought the devs may have collected some old schematics... Any hints are welcome!

Best,
Carsten

ascadol123, 2023-02-07:
Hi,
I think you be after these two Amiga Magazine Links which have a build a sampler project.
Mono and Stereo Modification using an analogue switch.

https://archive.org/details/cuamiga-magazine-039

https://archive.org/details/cuamiga-magazine-040

Kind Regards

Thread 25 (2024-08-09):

combine modifications

jnlundberg, 2024-08-09:
Im building OAS at the moment and would like to do the modifications mentioned here: conventional input stage, dc-offset fix, adjustable anti-aliasing filter.

Will it work to combine these or are additional steps needed?

I got 10 pcbs right away so I can afford to mess up once or twice when cutting the pcb.

gwEm303, 2024-08-09:
yes you can apply all at once, that's what I did :)

jnlundberg, 2024-08-09:
Sweet! Could please provide some pictures of a modded OAS? It would help me a lot.

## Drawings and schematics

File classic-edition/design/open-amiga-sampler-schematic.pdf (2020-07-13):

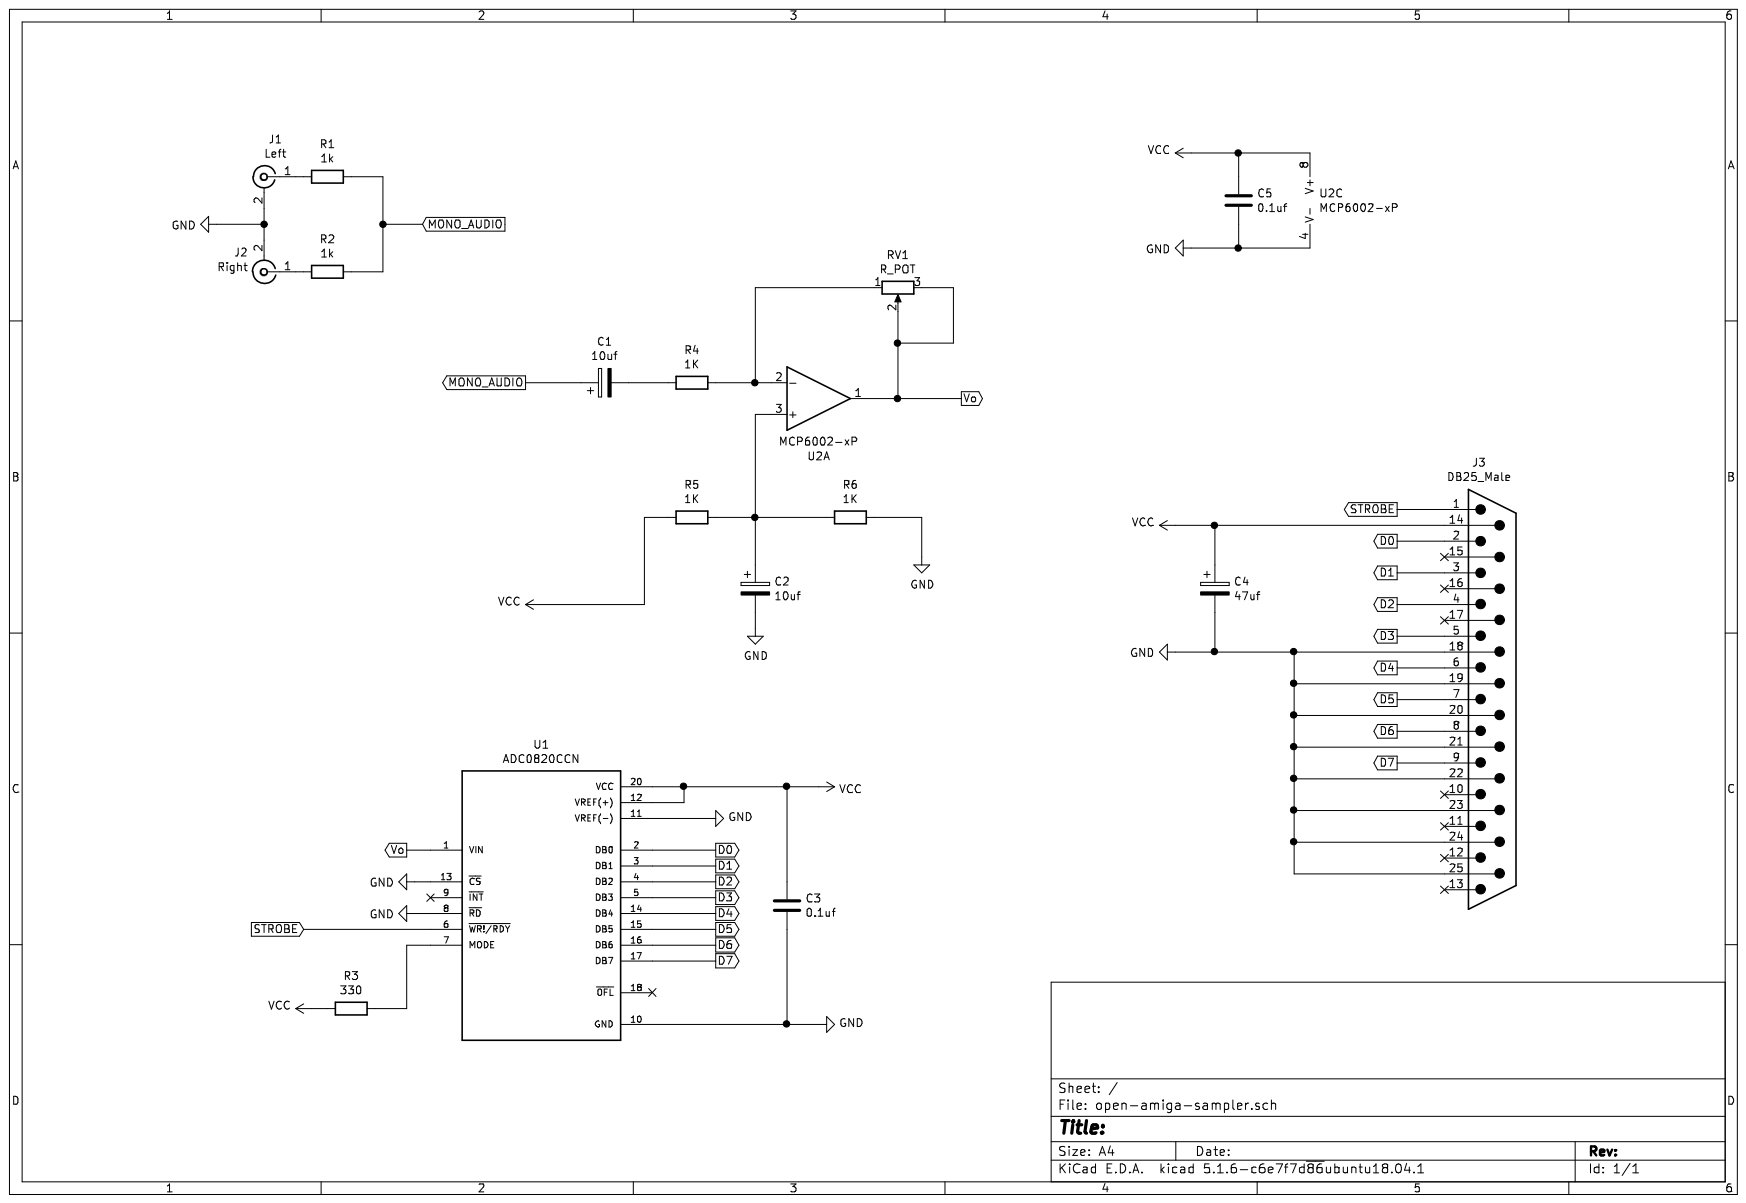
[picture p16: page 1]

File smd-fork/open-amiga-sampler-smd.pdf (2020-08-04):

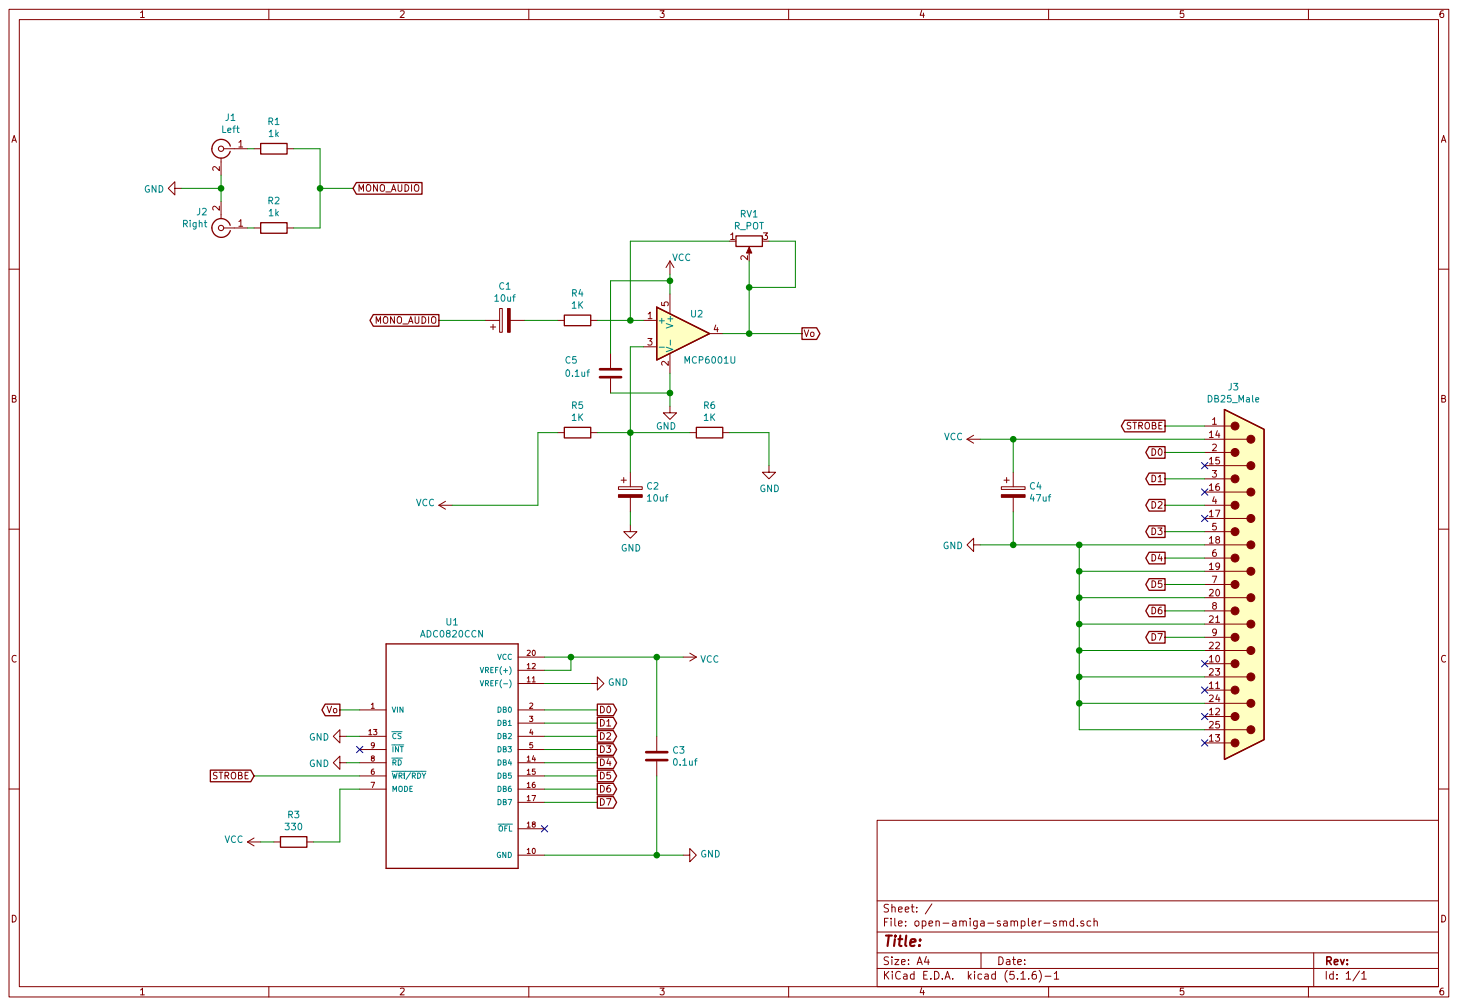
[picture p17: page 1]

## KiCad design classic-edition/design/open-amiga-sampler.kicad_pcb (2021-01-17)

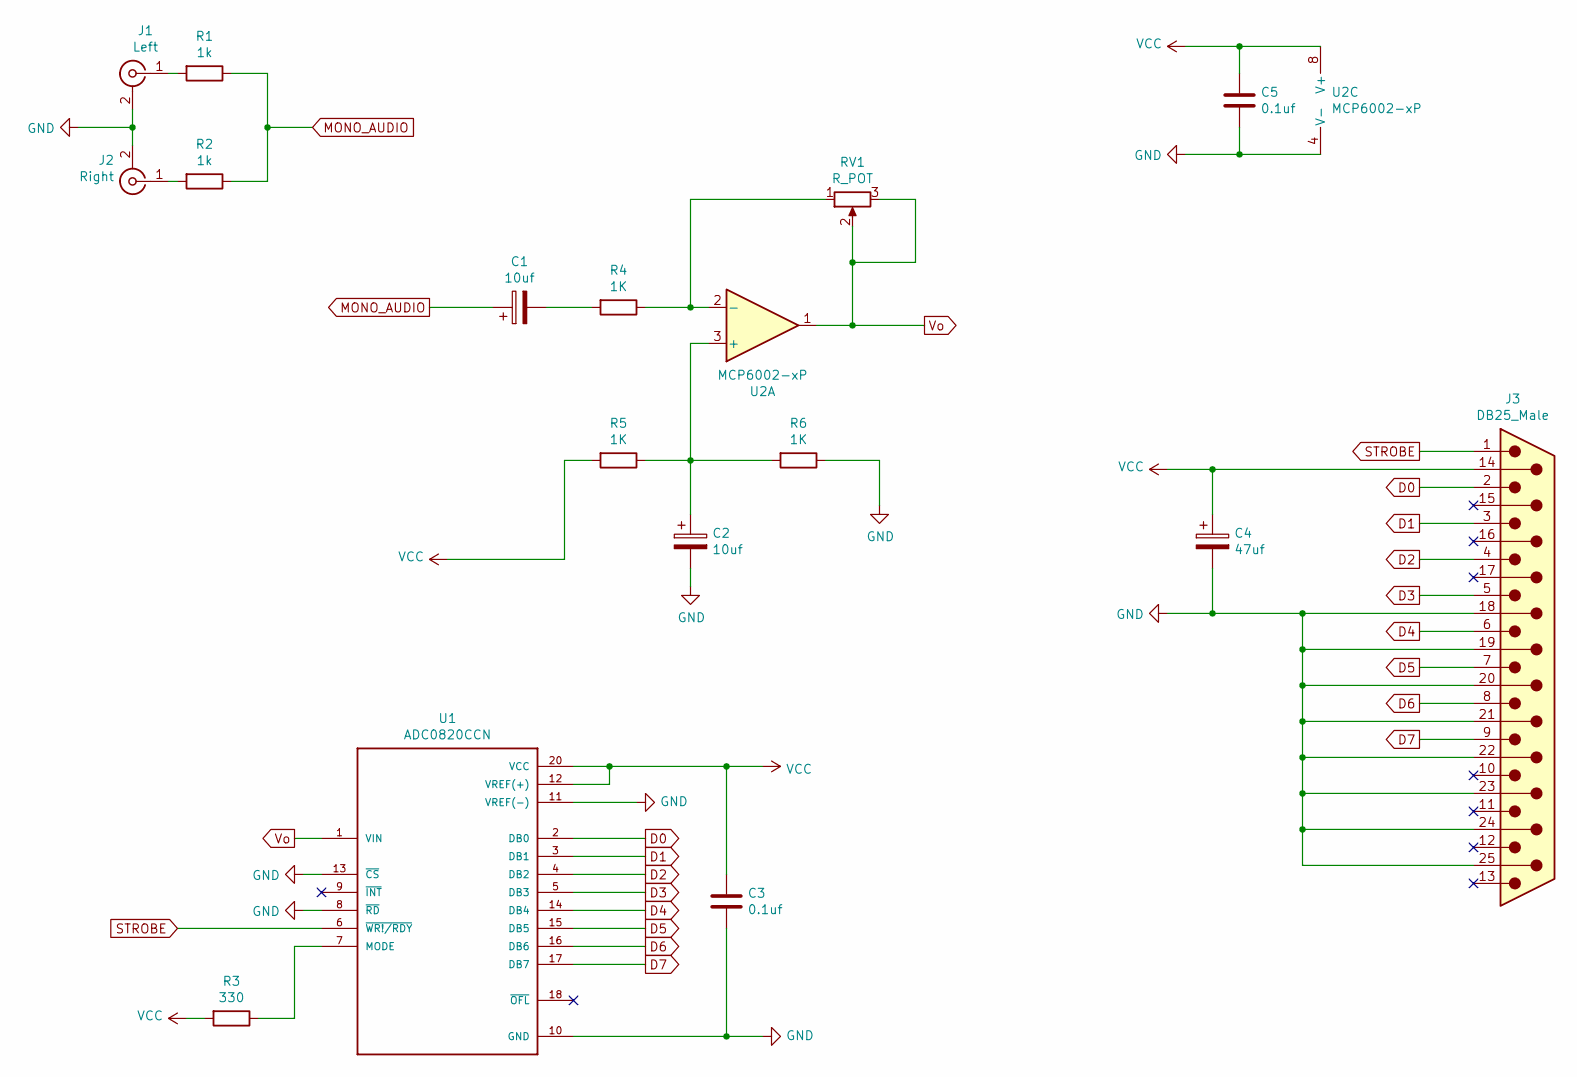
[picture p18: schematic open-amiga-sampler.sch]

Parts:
C1, C2: 10uf; CP_Radial_D4.0mm_P1.50mm
C3, C5: 0.1uf; C_Disc_D4.3mm_W1.9mm_P5.00mm
C4: 47uf; CP_Radial_D4.0mm_P1.50mm
J1: Left; Audio pads
J2: Right; Audio pads
J3: DB25_Male; DSUB-25_Male_EdgeMount_P2.77mm
R1, R2: 1k; R_Axial_DIN0207_L6.3mm_D2.5mm_P10.16mm_Horizontal
R3: 330; R_Axial_DIN0207_L6.3mm_D2.5mm_P10.16mm_Horizontal
R4, R5, R6: 1K; R_Axial_DIN0207_L6.3mm_D2.5mm_P10.16mm_Horizontal
RV1: R_POT; Pot pads
U1: ADC0820CCN; DIP-20_W7.62mm_Socket
U2: MCP6002-xP; DIP-8_W7.62mm_Socket

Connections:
D0: J3.2, U1.2 (DB0)
D1: J3.3, U1.3 (DB1)
D2: J3.4, U1.4 (DB2)
D3: J3.5, U1.5 (DB3)
D4: J3.6, U1.14 (DB4)
D5: J3.7, U1.15 (DB5)
D6: J3.8, U1.16 (DB6)
D7: J3.9, U1.17 (DB7)
GND: C2.2, C3.2, C4.2, C5.2, J1.2 (Ext), J2.2 (Ext), J3.18, J3.19, J3.20, J3.21, J3.22, J3.23, J3.24, J3.25, R6.1, U1.8 (~RD~), U1.10 (GND), U1.11 (VREF(-)), U1.13 (~CS~), U2.4 (V-)
MONO_AUDIO: C1.1, R1.1, R2.1
unnamed: C1.2, R4.2
unnamed: C2.1, R5.1, R6.2, U2.3 (+)
unnamed: J1.1 (In), R1.2
unnamed: J2.1 (In), R2.2
unnamed: R3.1, U1.7 (MODE)
unnamed: R4.1, RV1.1, U2.2 (-)
STROBE: J3.1, U1.6 (~WR!/RDY~)
VCC: C3.1, C4.1, C5.1, J3.14, R3.2, R5.2, U1.12 (VREF(+)), U1.20 (VCC), U2.8 (V+)
Vo: RV1.2, RV1.3, U1.1 (VIN), U2.1

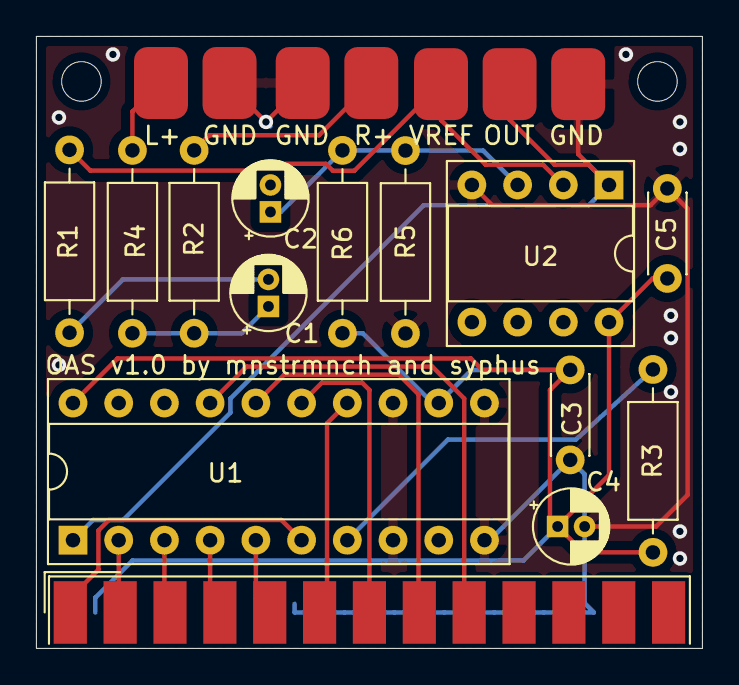
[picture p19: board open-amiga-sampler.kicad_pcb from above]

Board: 2 copper layers, 37.0 x 34.0 mm, 17 parts (0 on the bottom side), 19 nets.

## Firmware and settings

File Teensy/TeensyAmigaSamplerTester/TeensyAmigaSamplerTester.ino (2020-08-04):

/*
   http://github.com/echolevel/open-amiga-sampler
   
   Tested on Teensy 3.5 with microSD card
   USB type: 'Serial'
   CPU speed: '120Mhz'
   
   Everything else Arduino/Teensy default.
   
   This Teensy-based sampler tester mimics the behaviour of an Amiga parallel port during a 
   sampling operation (bytes are read and a a STROBE signal is emitted, as per the Amiga CIA 
   chip's behaviour). This is to reduce the risk of frying real Amigas' CIA chips during testing. 

   8 digital input pins connect straight to a DB25 connector's data pins, while three digital output pins 
   are converted from 3.3v to 5v before being connected to the DB25's STROBE, SELECT and PAPER_OUT pins.
   The DB25 connector also takes 5v directly from the Teensy's USB 5v input (this may need to be soldered 
   to the Teensy for a decent contact). See the OAS github for full docs/wiring diagrams.
   
   To convert raw: sox -t raw -r 16574.2757 -b 8 -c 1 -L -e signed-integer .\audio.raw .\audio.wav
   This tells sox to assume a samplerate that matches Protracker note C-3, and is calculated by 
   working out a PAL Amiga's clock speed divided by the note period from a LUT (214, in this case).
   -c is channel count 
   -L is endianness (irrelevant with 8bit values)
   -e is encoding, signed int

   Notes: the STROBE is sent by the Amiga's CIA chip at a fixed rate - ie the sample rate - after every
   data byte is read. On an Amiga this process is discrete/automatic, so from a programmer's perspective 
   the speed at which bytes are read (usually with an interrupt request - $DFF01E) is the desired sample 
   rate. But here we're doing it manually, sorta back to front. 

   The rate of that custom interrupt on the Amiga isn't actually the sample rate, it's the note period - 
   in other words, a value from a lookup table by which you divide the Amiga's PAL or NTSC clock frequency
   to get a sample rate. 

   5512.5 samplerate with 5 and 40 delays is roughly F-1 note

   Amiga clock: 3546895   
   B-3 period: 113
   F-1 period: 640

   B-3 samplerate: 31388.45
*/

#include <SPI.h>
#include <SD.h>
#include <SD_t3.h>

int strobePin = 9;
int paperPin = 10;
int selectPin = 11;
int speakerPin = 35;
int paperState = HIGH;
int selectState = LOW;

uint8_t inChar = 0;
int aBufferSize = 128000;
int bufferCount = 0;
int buffersWritten = 0;
uint8_t audioBuffer[128000];
const int chipSelect = BUILTIN_SDCARD;

// the setup routine runs once when you press reset:
void setup() {
    
  // 8 contiguous bits on Teensy 3.5:
  /*
     D0 2
     D1 14
     D2 7
     D3 8
     D4 6
     D5 20
     D6 21
     D7 5
  */
  pinMode(2, INPUT_PULLUP);
  pinMode(14, INPUT_PULLUP);
  pinMode(7, INPUT_PULLUP);
  pinMode(8, INPUT_PULLUP);
  pinMode(6, INPUT_PULLUP);
  pinMode(20, INPUT_PULLUP);
  pinMode(21, INPUT_PULLUP);
  pinMode(5, INPUT_PULLUP);  

  // These 3 control pins' logic output has to be converted to 5v 
  pinMode(strobePin, OUTPUT);
  // selectPin and paperPin control switching between left and right - tbc, but I think 
  // you alternate one high vs one low per read
  pinMode(selectPin, OUTPUT);
  pinMode(paperPin, OUTPUT);
  pinMode(speakerPin, OUTPUT);

  Serial.begin(9600);
  while (!Serial) {
    ; //wait for serial port to connect
  }


  Serial.print("Initialising SD card...");

  if (!SD.begin(chipSelect)) {
    Serial.println("Card failed, or not present");
    return;
  }
  Serial.println("card initialised");
  
}



// the loop routine runs over and over again forever:
void loop() {

  /*
   * In case you need to test each individual bit (can help diagnose continuity problems)
   * 
  String out;
  for (int i = 0; i < 8; i++) {
    out += digitalRead(i);
  }
  Serial.println(out);*/
  

  inChar = GPIOD_PDIR & 0xFF;


  if (bufferCount < aBufferSize) {

    

    audioBuffer[bufferCount] = inChar;

  } else {

    bufferCount = 0;
    
    File dataFile = SD.open("audio.raw", FILE_WRITE);
    
    if (buffersWritten == 0) {
      
      /* 
       * Unclear whether file seeking/overwriting works, so it's probably best to delete audio.raw from 
       * the SD card and touch a new one before each test (otherwise you might end up with multiple test
       * sessions being appended to the same file).
       * Linux/MacOS: rm audio.raw && touch audio.raw
       * Windows PowerShell: delete audio.raw; New-Item audio.raw -ItemType file
       */
       
      dataFile.seek(0);
      
    }
    
    if (dataFile) {
      Serial.println("Writing buffer to file");
      for (int i = 0; i < aBufferSize; i++) {
        
        dataFile.write( (int8_t)((int16_t) audioBuffer[i] - 128) );
        
      }
      
      dataFile.close();
      Serial.println("Done");
      buffersWritten++;
      
    } else {
      
      Serial.println("Error opening audio.raw");
      
    }


  }

  bufferCount++;  

  // For mono, don't switch these per cycle
  /*
  int tmp = paperState;
  paperState = selectState;
  selectState = tmp;
  */
  
  digitalWrite(selectPin, selectState); 
  digitalWrite(paperPin, paperState);

  digitalWrite(strobePin, LOW);
  delayMicroseconds(5);

  digitalWrite(strobePin, HIGH);
  delayMicroseconds(40);
  

}

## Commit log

2020-07-05 First go at a schematic
    [open-amiga-sampler.kicad_pcb, open-amiga-sampler.sch]
2020-07-05 Added gain potentiometer
    [open-amiga-sampler.sch]
2020-07-07 Fixed + and - on the op amp being the wrong way
    [open-amiga-sampler.sch]
2020-07-08 Added stereo mix circuit
    [open-amiga-sampler.sch]
2020-07-12 Initial go at a PCB layout.
    [open-amiga-sampler.kicad_pcb, open-amiga-sampler.sch]
2020-07-12 Missing bits for PCB layout
2020-07-13 Fixed op amp circuit
    [open-amiga-sampler.kicad_pcb, open-amiga-sampler.sch]
2020-07-13 Added some images and PDF schematic
2020-07-18 Initial case SCAD file
    [open-amiga-sampler.scad]
2020-07-24 Short readme for the KiCAD files
2020-07-24 Removed unfinished case design and moved schematic PDF
    [open-amiga-sampler.scad]
2020-07-24 Renamed schematic PDF and mentioned it in the readme
2020-07-26 Latest prototype case, still experimenting
    [open-amiga-sampler.scad]
2020-07-28 SMD-branch created
    initial pass on SMD-branch. second pass layout done.
    TODO: add casing and board-mount pot considerations.
    consider housing in a standard DB-shell
    [open-amiga-sampler-smd.kicad_pcb, open-amiga-sampler-smd.sch]
2020-07-28 Snap fit attempt 2
    [open-amiga-sampler.scad]
2020-07-29 tidied up positions and silkscreen
    Added new nilkscreen items and adjusted positions of a few components to avoid courtyard violations in DRC. upgraded VCC trace to be thicker
    [open-amiga-sampler-smd-B_Cu.gbr, open-amiga-sampler-smd-B_Mask.gbr, open-amiga-sampler-smd-B_Paste.gbr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]
2020-07-29 updated gerber plot
    [open-amiga-sampler-smd-B_Cu.gbr, open-amiga-sampler-smd-B_Mask.gbr, open-amiga-sampler-smd-B_Paste.gbr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]
2020-07-29 VCC improvements
    changed mailn bulk bypass cap to electrolytic. moved C3 to close to U1 Vcc. tweaked Vcc traces for better path. Silkscreen++
    [open-amiga-sampler-smd-B_Cu.gbr, open-amiga-sampler-smd-B_Mask.gbr, open-amiga-sampler-smd-B_Paste.gbr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]
2020-07-30 fixed unconnected grounds
    [open-amiga-sampler-smd.kicad_pcb]
2020-07-30 updated gerbers
    [open-amiga-sampler-smd-B_Cu.gbr, open-amiga-sampler-smd-B_Mask.gbr, open-amiga-sampler-smd-B_Paste.gbr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]
2020-07-30 uhhh some changes to the PCB
    [open-amiga-sampler-smd.kicad_pcb]
2020-07-30 Latest snap-fit design
    [open-amiga-sampler.scad]
2020-07-31 re-did board outline to (maybe) actually fit
    Using an accutare 3D model for a shell the board has been re-jigged to fit. still not tested against a real one though
    [open-amiga-sampler-smd-B_Cu.gbr, open-amiga-sampler-smd-B_Mask.gbr, open-amiga-sampler-smd-B_Paste.gbr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]
2020-07-31 added drill file to gerbers
    [open-amiga-sampler-smd.kicad_pcb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]
2020-08-04 Added Teensy tester code and some documentation
    Added Teensy tester code and some documentation
2020-08-04 Update README.md
    updated Teensy docs
2020-08-04 Update TeensyAmigaSamplerTester.ino
    tidied up Teensy code
2020-08-04 added stl files
    [OAS-Top shell.stl, OAS-lower-shell.stl]
2020-08-07 Yet another snapfit redesign
    [open-amiga-sampler.scad]
2020-08-09 updates to case stls
    minor PCB tweaks
    [OAS-Top shell.stl, OAS-lower-shell.stl, OAS-trimmer-knob.stl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]
2020-08-13 Yet another prototype case
    [open-amiga-sampler.scad]
2020-08-16 Another one
    [open-amiga-sampler.scad]
2020-08-25 Added case stl files
    [open-amiga-sampler-bottom.stl, open-amiga-sampler-top.stl]
2020-08-25 Working case design
    [open-amiga-sampler.scad]
2020-08-25 Moved Classic Edition files to their own dir
    [open-amiga-sampler-bottom.stl, open-amiga-sampler-top.stl, open-amiga-sampler.kicad_pcb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]
2020-08-30 Made case and phono distance wider, added built in spacer for pot
    [open-amiga-sampler.scad]
2021-01-17 Updated silk screen text
    [open-amiga-sampler.kicad_pcb]
